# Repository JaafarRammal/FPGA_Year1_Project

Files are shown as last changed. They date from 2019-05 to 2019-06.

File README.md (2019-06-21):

# Imperial College EIE-1: FPGA Flappy Bird

Demo: https://youtu.be/Gdy9L31zuA0

## Introduction

For our First Year Project in EIE at Imperial College, we are required to design a hardware system that performs real-time image processing on a video stream, implementing our proposed idea of an interactive game. Our system should perceive the real-world though a camera video stream and provide interactive output to the player via the HDMI monitor.

In response to the project requirements, we decided to build a replica of Flappy Bird. The classic game is a side-scroller where the player controls a bird by clicking on the screen to make the bird “flap up”, attempting to fly between columns of green pipes without hitting them. In our version, the only difference is that the player flaps their hands in front of the monitor to control the bird, feeding in an interactive and realistic experience for our flapping users.

Full Frame folders process the whole output frame. To add the game to the frame, we either use the vivado block (folders with in_game extension) or cv2 in the arm cpu (folders with \_cv2 extension)

## Directories:
- Full_Frame_CV2_720pi: This is the currently used version. FPGA detection on 720p. Game frame created and added by CPU with CV2. Includes final block design and schematic
- Full_Frame_CV2_1080pi: FPGA detection on 1080p. Game frame created and added by CPU with CV2
- Full_Frame_in_game_720pi: FPGA detection on 720p. Game frame added by FPGA after being shared by CPU through MMIO
- Green_Wrist_Detection: FPGA detection initial block test
- Jupyter_Notebooks: backups of Jupyter notebooks
- Python_Game: animating the Flappy Bird game with python. Contains a sprite-based version (import and assemble assets to form the frame) and a pixel-based version (draw all the elements pixel by pixel for every frame)
- Python_Tests: quick tests of our algorithms in python before implementing with Vivado
- Separate_Objects: 3 stages algorithm to distinghuish different bracelets of same color (a step to a multiplayer mode)
- Skin_Detection: FPGA block for HSV skin detection

## Using on your board:

### Setting up: 

- For the Jupyter Notebook use _./Jupyter_Notebooks/Game_v3.ipynb_
- For the overlay use _./Full_Frame_CV2_720pi/game.bit_ and _./Full_Frame_CV2_720pi/game.tcl_ (do NOT use v2)
- Print the green bracelets using the step file _/bracelets.step_ (best results with _ZIRO Fluo Green PLA_)
- In the same notebook folder create a text file named _highscores.txt_ and initialize it manually with 3 lines of 0 (as in 0/n0/n0/n)
- You are now ready to play!

PS: if you encounter problems with the highscore file or process, use the notebook _./Jupyter_Notebooks/Game_v2.ipynb_ as it runs the exact same game tools but without the highscore feature 

### How to play:

- Run the notebook sections in order one by one. Allow for each section a reasonable runtime and check for any errors
- When the game starts running, there is no more need for the laptop ethernet connection: you can unplug your board and keep it running by itself on power!

The game has a play mode and a settings mode, toggled by switch 0

#### Play mode:

- Flap your hands to make the bird fly and avoid as many pipes as you can. That simple to use!
- When you score a highscore, it will save for the next game session
- You can check the detection on the bottom left screen. If the background presents white noise or your flap feels weird, jump to the settings mode to change the tresholds using switch 0
- To force exit a game to the main menu, press button 1
- To force exit the whole process, press button 0 (this will end the whole pynq board process)

#### Settings mode:

- Change difficulty with button 0 between easy, medium, and hard
- Select with switch 1 which treshold to change (_Color treshold_ for hands detection and _Height treshold_ for flap detection)
- Use buttons 2/3 to increase/decrease the treshold value and button 1 to set it back to default
- For the color treshold, the best result is when the whole detection background is black and only your bracelets are white
- For the height treshold, you will be changing your "flap speed and range" (in other words how down you flap between two frames). A higher treshold means you have to flap stronger, faster, and on a large vertical distance to initiate the flap, and vice-versa. When changing the height treshold, you can test the flap by observing the 4 green LEDs on the board: these will blink when you flap
- You are now ready to play! Jump to _play mode_ using switch 0

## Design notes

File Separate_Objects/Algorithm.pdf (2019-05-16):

The current algorithm uses two detection stages as in a simple network in order to distinguish the two bracelets of same color. The first stage is a mask to identify whether a pixel is that of a bracelet or not (as currently used in our single player mode). The mask output is a Boolean map of the image with 1 for bracelet pixels and 0 for the others. The second stage identifies independent groups of pixels in the Boolean map. Scan the map, and if a pixel is found to be 1, assign a color, mark as zero, and search all neighbor pixels using the same color until none are found. Carry on in the map until reaching the end of it.

The second stage was implemented over three phases:

1. A recursive implementation: check the current pixel and then check the neighbors by calling the same function with new coordinates (full code on GitHub), based on a depth-first-search
The problem with this simple, artistic implementation is that it is impossible to synthesis because of the recursive calls (how would you translate recursive calls and unknown, maybe infinite stack storage for previous function calls on hardware)
2. It was clear that a recursive implementation cannot be synthesized. The next step was to implement this function in the main in a while loop, to avoid stacking the variables of long recursive calls. The implementation became breath-first-search using a queue (FIFO protocol: first pixel in, first pixel out) but a similar method could work with a stack DFS implementation. When a pixel is found, it is pushed to the queue, which enters a while-loop. The loop goes on, adding neighbor pixels to the queue and checking them, until the queue is empty (no more valid neighbors to check) (full code on GitHub).
Another problem showed up: the queue structure couldn’t be synthesized. A vector was therefore used to implement the queue. The synthesis would complete without any solution. The explanation is because a vector (and therefore a queue) is a variable-length memory structure: the number of elements cannot be predicted for hardware allocation, and after adding or removing an element, a whole remapping takes place to readjust the indexing of elements
3. The solution was therefore to implement a queue from a static array with a known size. The idea is to use to index-followers: one for the index to read at, and one for the index to write at. These indexes "loop" around the array when they reach the end. The following is an illustration for the following actions on a queue ("read" means queue.front() followed by queue.pop() ):

Queue actions: START, push(3), push(4), push (2), push(6), read(), read(), push(1), read(), push(9), read(), read(), read(). Array illustration (size 4). Reader index (queue head) in green, writer index (queue tail) in red (yellow: both are on same cell):

Queue Actions | Index 0 | Index 1 | Index 2 | Index 3 | Queue head | Queue tail | Output
START | ? | ? | ? | ? | 0 | 0 | NA
Push(3) | | | ? | ? | 0 | 1 | NA
Push(4) | 3 | 4 | ? | ? | 0 | 2 | NA
3 | ?
Push(2) | 3 | 4 | 2 | ? | 0 | 3 | NA
Push(6) | 3 | 4 | 2 | 6 | 0 | 0 | NA
Read() | 3 | 4 | 2 | 6 | 1 | 0 | 3
Read() | 3 | 4 | 2 | 6 | 2 | 0 | 4
Push(1) | 1 | 4 | 2 | 6 | 2 | 1 | NA
Read() | 1 | | 2 | | 3 | 1 | 2
Push(9) | 1 | 9 | 2 | 6 | 3 | 2 | NA
4 | 6
Read() | 1 | 9 | 2 | 6 | 0 | 2 | 6
Read() | 1 | 9 | 2 | 6 | 1 | 2 | 1
Read() | 1 | 9 | 2 | 6 | 2 | 2 | 9

The final question is: how do we track that we the process is done? (in part 2 we checked when the queue was empty). Well, notice the following example for the same process but for an array of 5 entries:

Queue Actions | Index 0 | Index 1 | Index 2 | Index 3 | Index 4 | i_read | i_write | Output
START | | ? | ? | ? | ? | 0 | 0 | NA
Push(3) | 3 | ? | ? | ? | ? | 0 | 1 | NA

?

Push(4) | 3 | 4 | ? | ? | ? | 0 | 2 | NA
Push(2) | 3 | 4 | 2 | ? | ? | 0 | 3 | NA
Push(6) | 3 | 4 | 2 | 6 | ? | 0 | 4 | NA
Read() | 3 | 4 | 2 | 6 | ? | 1 | 4 | 3
Read() | 3 | 4 | 2 | 6 | ? | 2 | 4 | 4
Push(1) | 3 | 4 | 2 | 6 | 1 | 2 | 0 | NA
Read() | 3 | 4 | 2 | 6 | 1 | 3 | 0 | 2
Push(9) | 9 | 4 | 2 | 6 | 1 | 3 | 1 | NA
Read() | 9 | | 2 | 6 | | 4 | 1 | 6
Read() | 9 | 4 | 2 | 6 | 1 | 0 | 1 | 1
4 | 1
Read() | 9 | 4 | 2 | 6 | 1 | 1 | 1 | 9

Notice how the two indexes meet only when the queue is empty if the array is big enough to avoid overlaying the indexes during the process. The queue can now be implemented using a static array! (Full code on GitHub)

The size of the array is chosen by estimating the size of the detected objects and therefore the maximum number of pixels that will be held in the queue awaiting check. A quick mathematical demonstration shows that for an A (blue) by B (green) canvas to be scanned, the following conclusion applies.

Let N = $%&
' , and suppose the non-valid neighbors are not added for checking. The number of maximum elements in the queue will be S)** = 1 + 3 + 5 + 7 + ⋯ + (2N − 1). To find the sum, let S'6 = 1 + 2 + 3 + ⋯ + 2N = (2 + 4 + ⋯ + 2N) + 81 + 3+. . +(2N − 1)9 = 2(1 + 2 + 3 + ⋯ + N) + S)** ⇒ S'6 =
2S6 + S)** ⇒ S)** = S'6 − 2S6 = '6('6%;)
' | − 2 ⁶⁽⁶%;)
' | = N'

On our screen, the dimensions are 360x640 pixels for the canvas. An object may cover at most ;
;< of the canvas,
or 14 400 pixels. Squaring this value gives an array size of 207,360,000. Quite big… can we do better? Yes. Supposed at some point the array was small enough to allow overwriting pixels that were to be scanned. These will have neighbors that will add them back to the array! After trial and error, the size of the array could be reduced down to 115,200 and still offer great results
4. Further work:

Two other stages are to be added in order to perform a smooth multiplayer mode:
- A stage that checks every detected object's number of pixels: if it too small, it corresponds to noise or misdetection, and is deleted (made black)
- A stage that tracks each object movements vectors, predicting the object's next position environment (in a span of pixels). This will allow removing objects color switching (as when one is detected before the other and then after it)
Stage 0: Image Input | Stage 1: Color detection

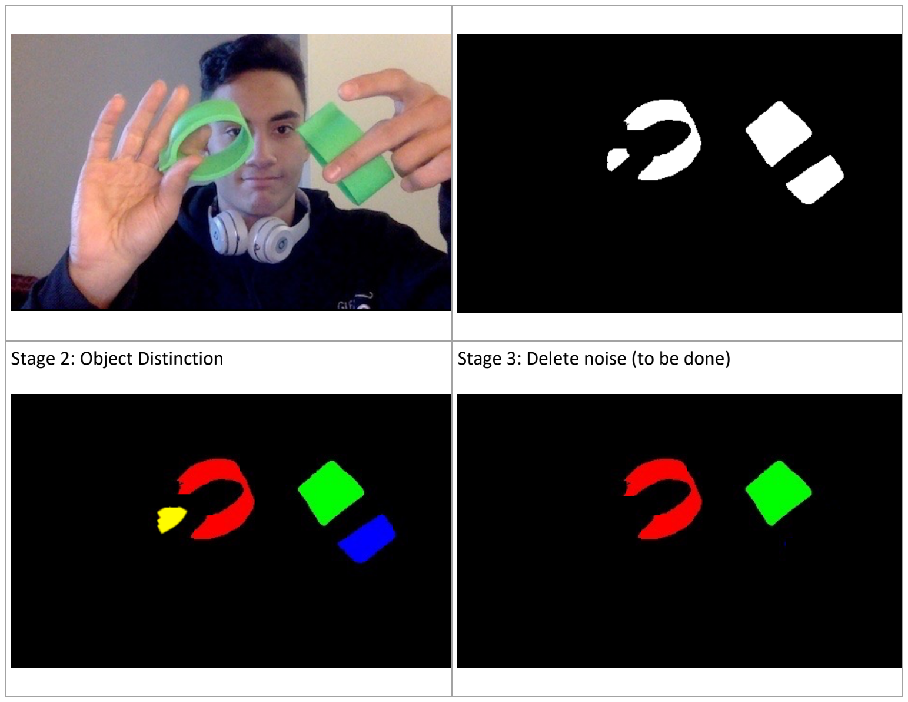
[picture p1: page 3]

Stage 2: Object Distinction | Stage 3: Delete noise (to be done)

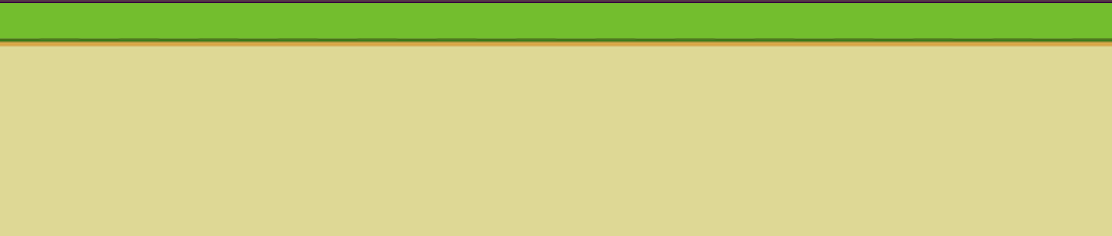
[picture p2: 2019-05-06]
Python Game/assets/base.png

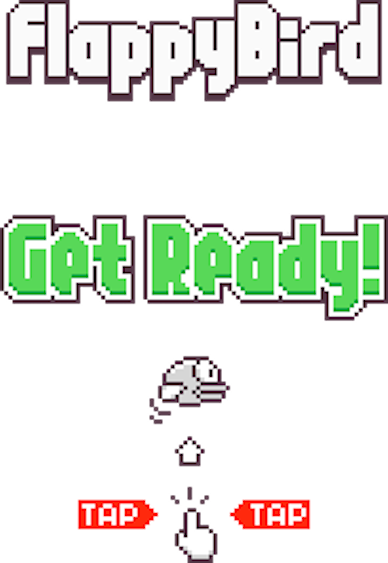
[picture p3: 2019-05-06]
Python Game/assets/message.png

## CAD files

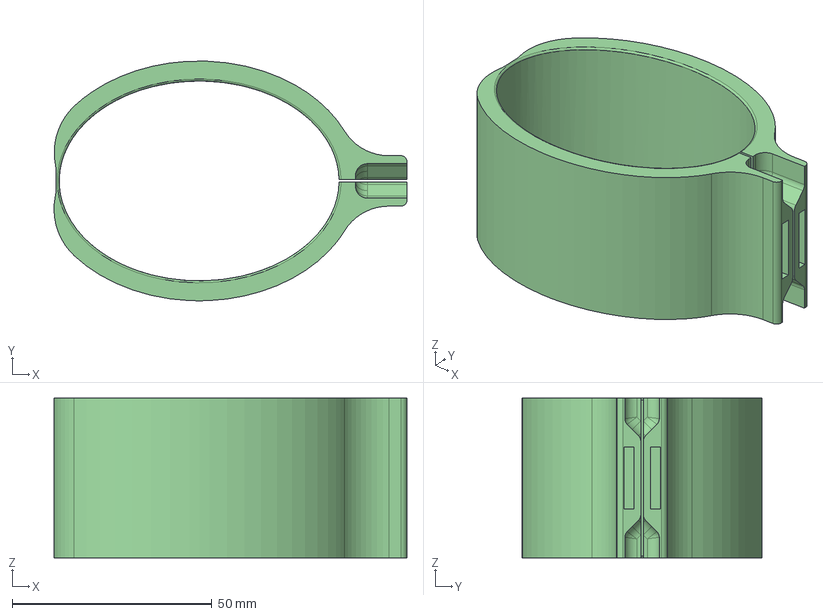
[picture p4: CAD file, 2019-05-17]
bracelets.step
88.3 x 60.0 x 40.0 mm

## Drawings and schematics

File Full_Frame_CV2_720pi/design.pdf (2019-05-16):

# Vaux0 Vaux1 Vaux5 Vaux6 Vaux8 Vaux9 Vaux12 Vaux13 Vaux15 Vp_Vn

### arduino_direct_iic

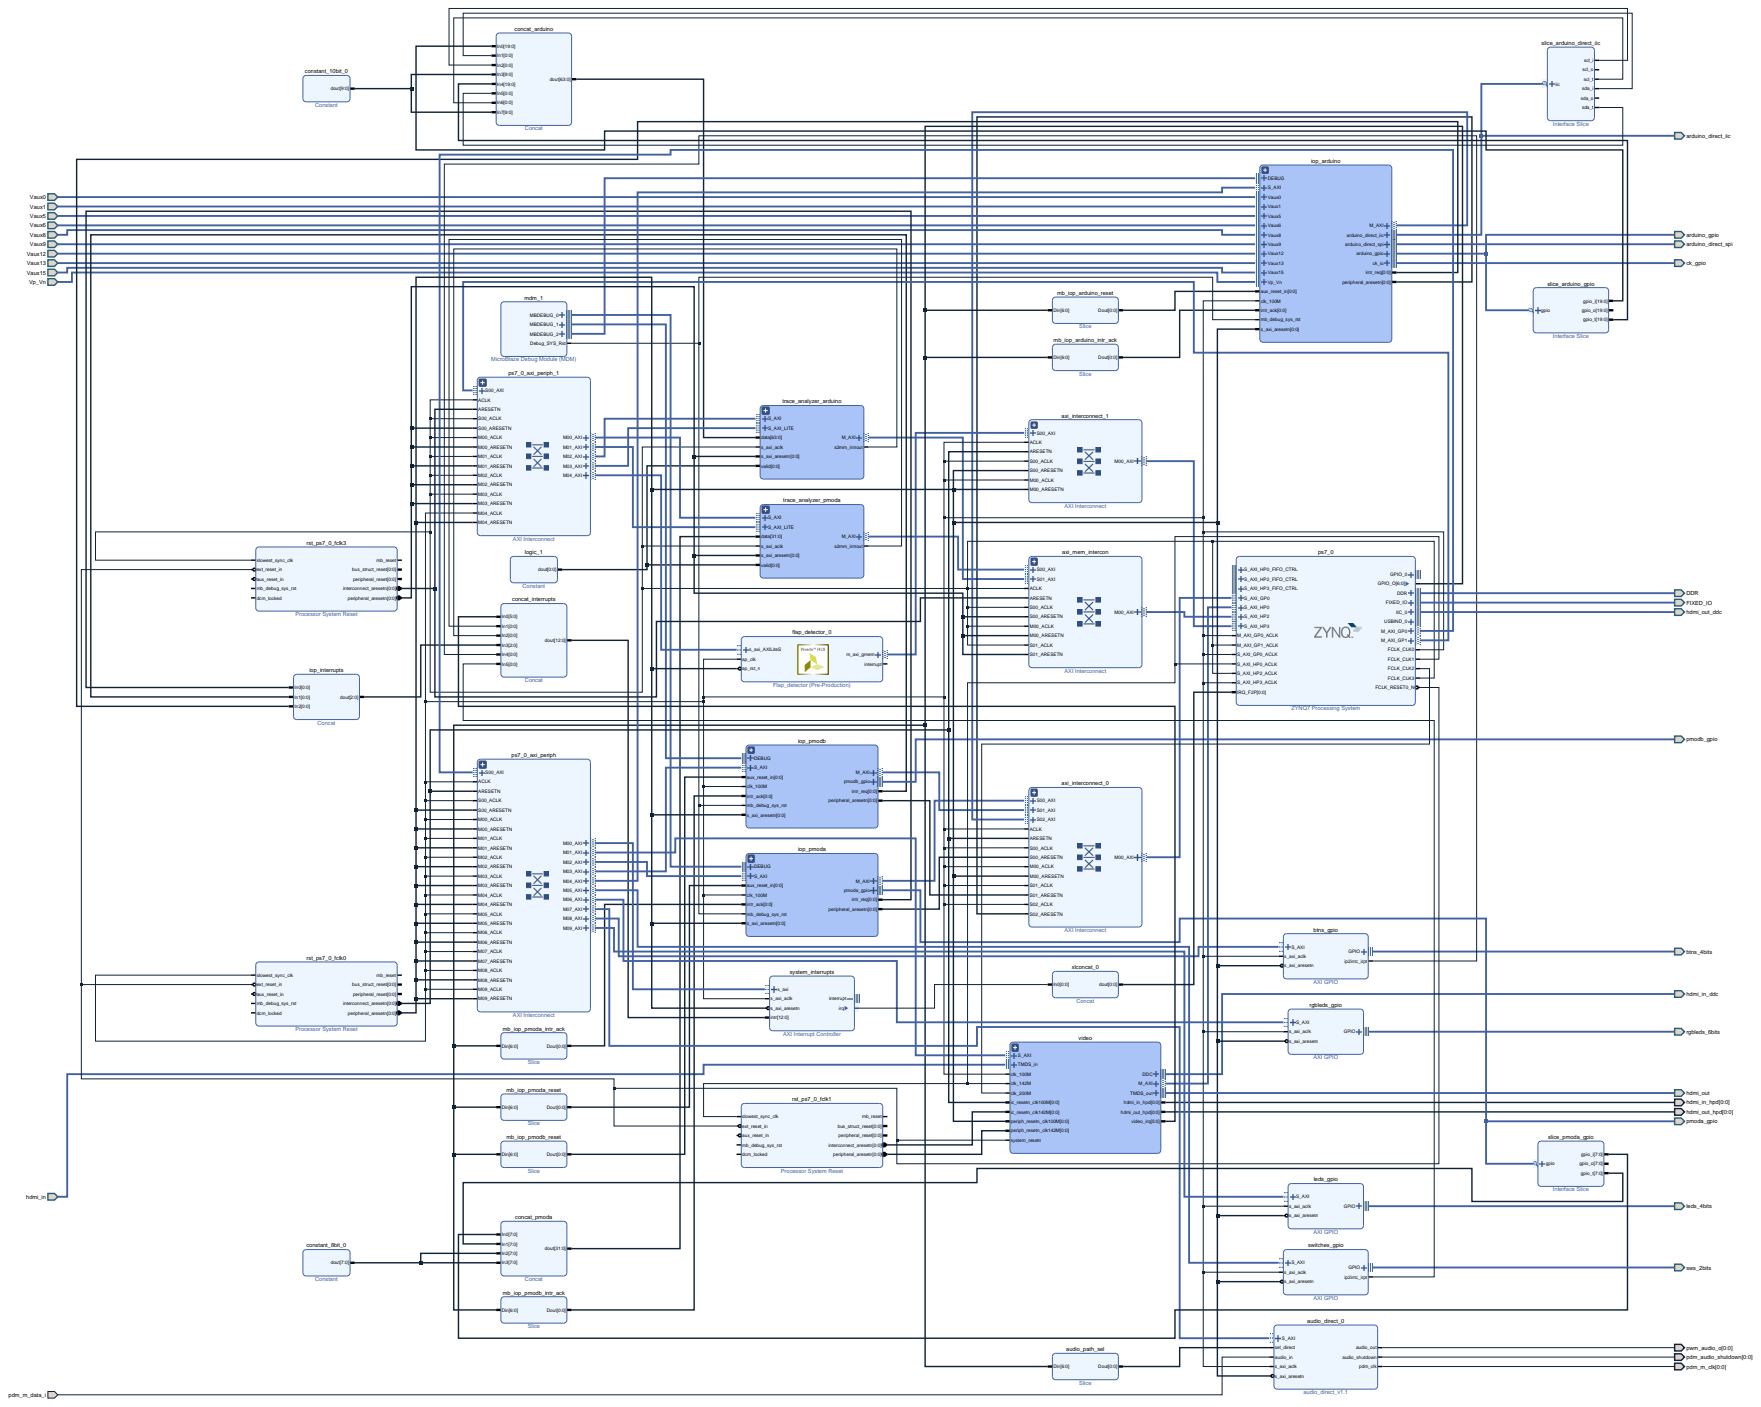
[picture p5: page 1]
DDR FIXED_IO; arduino_direct_spi; arduino_gpio; audio_direct_0; audio_direct_v1.1; S_AXI sel_direct audio_in; audio_out audio_shutdown; s_axi_aclk; pdm_clk; s_axi_aresetn; audio_path_sel; Slice; Din[6:0]; Dout[0:0]; axi_interconnect_0; AXI Interconnect; S00_AXI; M00_AXI; S01_AXI S02_AXI ACLK; ARESETN; S00_ACLK; S00_ARESETN M00_ACLK M00_ARESETN; S01_ACLK; S01_ARESETN; S02_ACLK; S02_ARESETN; axi_interconnect_1; ACLK; axi_mem_intercon; S01_AXI ACLK; btns_gpio; AXI GPIO; S_AXI; GPIO; ip2intc_irpt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

MicroBlaze Debug Module (MDM)

Processor System Reset

AXI Interrupt Controller

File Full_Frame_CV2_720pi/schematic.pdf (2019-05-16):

109876543210 | 0123456789
19 | 0123456789

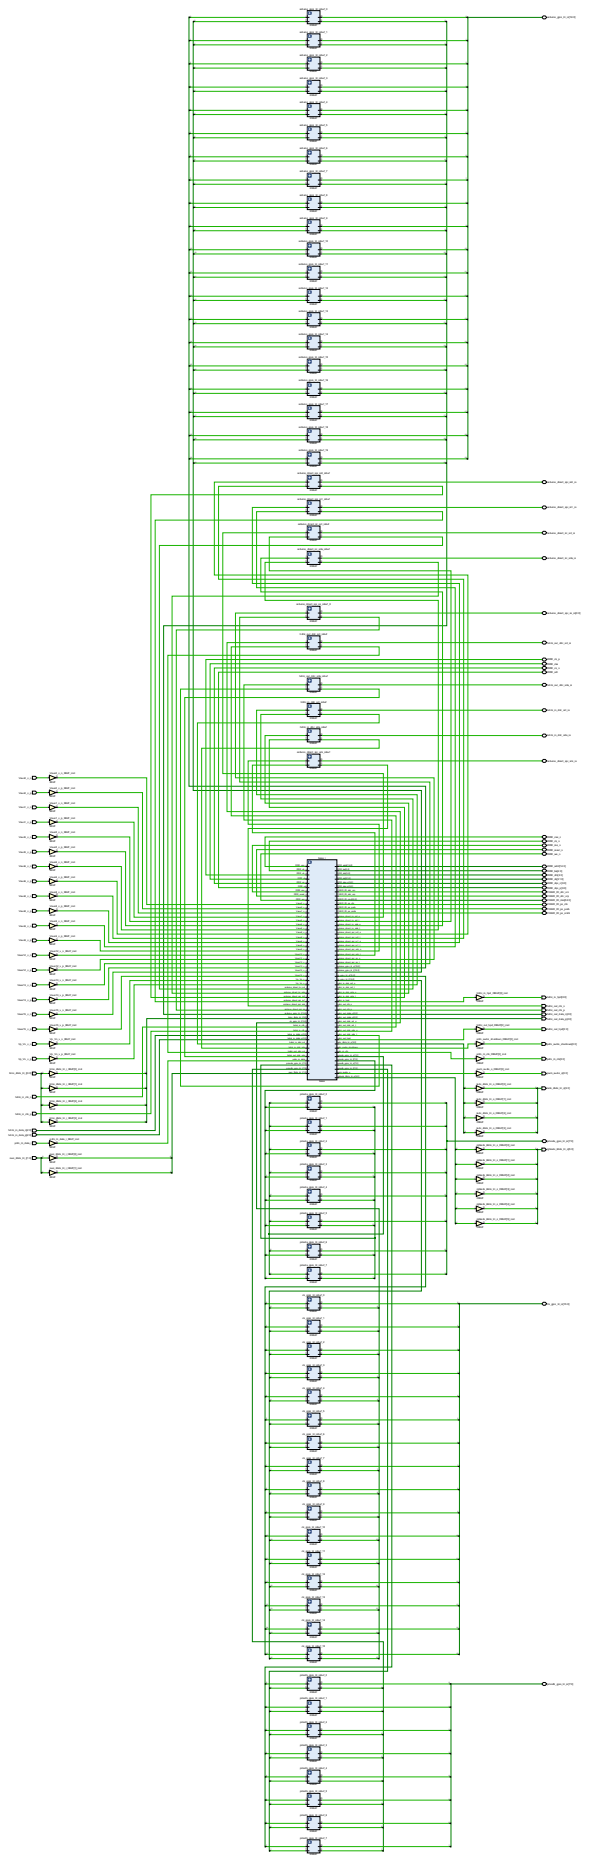
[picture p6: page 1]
Vaux0_v_n Vaux0_v_p Vaux1_v_n Vaux1_v_p Vaux5_v_n Vaux5_v_p Vaux6_v_n Vaux6_v_p Vaux8_v_n Vaux8_v_p Vaux9_v_n Vaux9_v_p Vaux12_v_n Vaux12_v_p Vaux13_v_n Vaux13_v_p Vaux15_v_n Vaux15_v_p Vp_Vn_v_n Vp_Vn_v_p; btns_4bits_tri_i[3:0]; hdmi_in_clk_n; hdmi_in_clk_p; hdmi_in_data_n[2:0] hdmi_in_data_p[2:0] pdm_m_data_i; sws_2bits_tri_i[1:0]; Vaux0_v_n_IBUF_inst; IBUF I; O Vaux0_v_p_IBUF_inst; O Vaux1_v_n_IBUF_inst; O Vaux1_v_p_IBUF_inst; O Vaux5_v_n_IBUF_inst; O Vaux5_v_p_IBUF_inst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

hdmi_in_ddc_sda_iobuf

arduino_direct_spi_sck_iobuf IOO IT

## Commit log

2019-03-28 Created frame function
    Takes in input different positions to combine assets into a single frame
2019-05-09 Optimized
    Removed some of the inputs. Even though the latency doesn't change, the overall FPS will be better, since we have less inputs to communicate to the FPGA from the CPU for every frame
2019-05-16 Rename Python Game/camera.py to Python_Tests/camera.py
